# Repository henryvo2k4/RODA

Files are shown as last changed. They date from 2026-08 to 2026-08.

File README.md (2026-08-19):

# RODA

<div align="center">
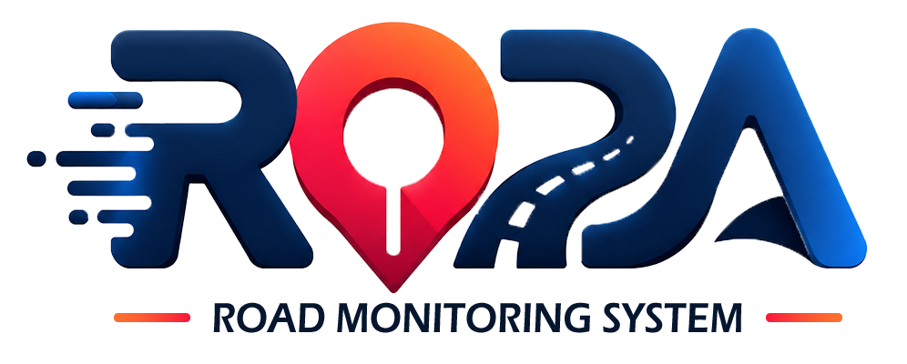
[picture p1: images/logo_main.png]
RODA Logo
  

  <h1>RODA (Road Monitoring System)</h1>
  <p><b>An End-to-End Intelligent Transportation System (ITS) for Real-time Urban Infrastructure Monitoring</b></p>
  
  
  
  
  
  
  
</div>

---

## Overview

**RODA** is an IoT-GIS road monitoring system developed as an individual
graduation project.

The system combines embedded IoT devices, cloud services, AI-based image
verification, GIS technologies, Web applications, and an Android application
to monitor and manage urban road incidents.

### Supported Incidents

| Incident | Detection Method |
|---|---|
| 🕳️ Pothole | ESP32 + MPU6050 |
| 🌊 Flooding | ESP32 + JSN-SR04T |
| 🚧 Construction | AI image verification |
| 📍 Road incidents | GPS / GIS |

---

## System Architecture

RODA consists of four major layers:

```text
┌───────────────────────┐
│    EMBEDDED LAYER     │
│                       │
│  Mobile Node          │
│  Fixed Node           │
└───────────┬───────────┘
            │
            │ HTTPS / REST / JSON
            ▼
┌───────────────────────┐
│     CLOUD LAYER       │
│                       │
│  Supabase             │
│  PostgreSQL           │
│  Storage              │
└───────────┬───────────┘
            │
      ┌─────┴─────┐
      ▼           ▼
┌───────────┐ ┌────────────────┐
│ AI / GIS  │ │ APPLICATIONS   │
│           │ │                │
│ YOLOv8    │ │ Android        │
│ Leaflet   │ │ Web Dashboard  │
└───────────┘ └────────────────┘
```

---

# Embedded System

RODA uses two ESP32-based IoT nodes designed for different monitoring
scenarios.

## Mobile Node

The Mobile Node is designed to be installed on a moving vehicle for
road-surface monitoring.

### Hardware

- ESP32
- MPU6050
- NEO-6M GPS
- MicroSD
- 18650 Li-ion Battery
- TP4056

### Functions

- Detect potholes from vehicle acceleration.
- Acquire GPS coordinates.
- Store incident data locally.
- Synchronize stored data with the cloud.
- Continue monitoring without an active Internet connection.

### Pothole Detection

The MPU6050 continuously measures acceleration.

The system processes the Z-axis acceleration and triggers a pothole event
when the configured threshold is exceeded.

```text
MPU6050
   │
   ▼
Acceleration Sampling
   │
   ▼
Z-axis Processing
   │
   ▼
Threshold Detection
   │
   ├── Normal
   │
   └── Pothole Detected
            │
            ▼
         Read GPS
            │
            ▼
      Store to MicroSD
```

---

## Store-and-Forward

A key feature of the Mobile Node is the **Store-and-Forward architecture**.

The system separates road monitoring from cloud synchronization.

### Sensing

```text
Vehicle Moving
      │
      ▼
Read MPU6050
      │
      ▼
Detect Pothole
      │
      ▼
Read GPS
      │
      ▼
Store Lat / Lng / Time
to MicroSD
```

### Synchronization

```text
Vehicle Stops
      │
      ▼
Start Synchronization
      │
      ▼
Enable Wi-Fi
      │
      ▼
Read Local Data
      │
      ▼
Create JSON Payload
      │
      ▼
HTTP POST
      │
      ▼
Supabase
```

This allows the device to continue collecting incident data during network
outages and synchronize the stored records when connectivity is restored.

---

# Fixed Node

The Fixed Node is designed for outdoor deployment at flood-prone locations.

### Hardware

- ESP32
- JSN-SR04T waterproof ultrasonic sensor
- Solar panel
- 18650 Li-ion battery
- Power management circuitry

### Functions

- Measure water level.
- Calculate flooding depth.
- Detect configurable flood thresholds.
- Send incident alerts to the cloud.
- Operate periodically using Deep Sleep.

### Flood Detection

```text
JSN-SR04T
    │
    ▼
Measure Distance
    │
    ▼
Compare with Reference Distance
    │
    ▼
Calculate Water Level
    │
    ├── Normal
    │
    └── Flood Detected
             │
             ▼
       Create JSON Payload
             │
             ▼
        HTTPS / REST API
             │
             ▼
          Supabase
```

---

# Low-Power Design

The Fixed Node uses periodic wake-up and **ESP32 Deep Sleep** to reduce
energy consumption.

```text
       ┌──────────────┐
       │  Deep Sleep  │
       └──────┬───────┘
              │
              ▼
         Wake Up Timer
              │
              ▼
         Read Sensor
              │
              ▼
       Process Water Level
              │
              ▼
        Send Data via Wi-Fi
              │
              ▼
         Return to Sleep
```

### Measured Results

| State | Current |
|---|---:|
| Active / Wi-Fi | ~120 mA |
| Deep Sleep | ~15 µA |
| Average | ~1.35 mA |

---

# Cloud & Data Pipeline

RODA uses **Supabase** as the cloud backend.

### Components

- PostgreSQL
- REST API
- Supabase Storage
- HTTPS
- JSON

### Data Flow

```text
ESP32
  │
  │ JSON
  ▼
HTTPS REST API
  │
  ▼
Supabase
  │
  ├── PostgreSQL
  ├── Storage
  └── API
       │
       ├── Android
       ├── Web
       └── AI Service
```

Each IoT node is identified using a unique `device_id`.

Example payload:

```json
{
  "device_id": "NODE_CODINH_01",
  "lat": 10.732,
  "lng": 106.721,
  "type": "Flood",
  "status": "approved",
  "description": "Flood detected",
  "created_at": "2026-05-18T14:30:00+07:00"
}
```

---

# AI & GIS

## AI Incident Verification

RODA integrates an AI pipeline for image-based incident verification.

### Stack

- Python
- YOLOv8
- Hugging Face

### Detection Classes

- Pothole
- Flood
- Construction

### Pipeline

```text
Incident Image
      │
      ▼
AI Service
      │
      ▼
YOLOv8
      │
      ▼
Object Detection
      │
      ▼
Confidence Evaluation
      │
      ▼
Incident Verification
      │
      ▼
Cloud Status Update
```

---

## GIS

The GIS layer provides geographic visualization and spatial processing of
road incidents.

### Technologies

- OpenStreetMap
- Leaflet.js
- Turf.js
- OSRM
- Overpass API
- OSMDroid

### Features

- Interactive incident map
- GPS-based incident markers
- Road visualization
- Route calculation
- Road snapping
- Spatial processing
- Incident filtering

---

# Applications

## Android Application

<p align="center">
  
</p>

The Android application provides mobile access to the RODA platform.

### Features

- Report road incidents
- Capture incident images
- Acquire location
- View incidents on GIS maps
- Access cloud data
- Submit images for AI verification
- Routing and map interaction

### Technology

**Java · Android SDK · OSMDroid · OkHttp**

---

## Web Dashboard

The Web Dashboard provides centralized monitoring and management of road
incident data.

### Features

- GIS incident visualization
- Incident management
- Device monitoring
- Data filtering
- Road-event visualization
- Administrative functions

### Technology

**HTML · CSS · JavaScript · Leaflet.js · OpenStreetMap · REST API**

---

# Communication

RODA integrates multiple communication interfaces across the embedded and
cloud layers.

| Interface | Application |
|---|---|
| **I²C** | ESP32 ↔ MPU6050 |
| **UART** | ESP32 ↔ GPS |
| **SPI** | ESP32 ↔ MicroSD |
| **Wi-Fi** | ESP32 ↔ Internet |
| **HTTPS** | IoT ↔ Cloud |
| **REST API** | Cloud ↔ Applications |
| **JSON** | Data Exchange |

---

# Results

## Mobile Node

The Store-and-Forward mechanism was tested under different operating
conditions.

| Test | Result |
|---|---:|
| 30 km/h | 10/10 synchronized |
| 50 km/h | 7/7 synchronized |
| Network unavailable | 15/15 synchronized |
| Observed data loss | **0%** |

## Fixed Node

JSN-SR04T measurements produced errors of approximately:

**0.1 – 0.3 cm**

| Scenario | Actual | Measured | Error |
|---|---:|---:|---:|
| Dry road | 100 cm | 99.8 cm | 0.2 cm |
| Water rising | 98 cm | 98.1 cm | 0.1 cm |
| Light flooding | 94 cm | 94.3 cm | 0.3 cm |
| Deep flooding | 79 cm | 79.2 cm | 0.2 cm |

---

# Technology Stack

### Embedded

`C/C++` `ESP32` `MPU6050` `JSN-SR04T` `NEO-6M` `MicroSD`
`I²C` `UART` `SPI` `Wi-Fi` `Deep Sleep`

### Cloud

`Supabase` `PostgreSQL` `REST API` `HTTPS` `JSON`
`Supabase Storage`

### AI

`Python` `YOLOv8` `Hugging Face`

### GIS

`OpenStreetMap` `Leaflet.js` `Turf.js` `OSRM`
`Overpass API` `OSMDroid`

### Applications

`Java` `Android SDK` `HTML` `CSS` `JavaScript` `Vercel`

---

# Repository Structure

```text
RODA/
│
├── hardware/
│   ├── NodeDiDong/
│   ├── NodeCoDinh/
│   └── schematics/
│
├── android/
│
├── web/
│
├── ai/
│
├── images/
│   ├── logo_main.png
│   ├── system-architecture.png
│   ├── mobile-node.jpg
│   ├── fixed-node.jpg
│   ├── web-dashboard.png
│   └── android-app.png
│
└── README.md
```

---

# Project Status

| Component | Status |
|---|---|
| Mobile IoT Node | ✅ Completed |
| Fixed IoT Node | ✅ Completed |
| Store-and-Forward | ✅ Completed |
| Cloud Backend | ✅ Completed |
| AI Verification | ✅ Completed |
| GIS Platform | ✅ Completed |
| Android Application | ✅ Completed |
| Web Dashboard | ✅ Completed |

---

# Author

<p align="center">
  <strong>Henry</strong><br>
  Embedded Systems & IoT Developer
</p>

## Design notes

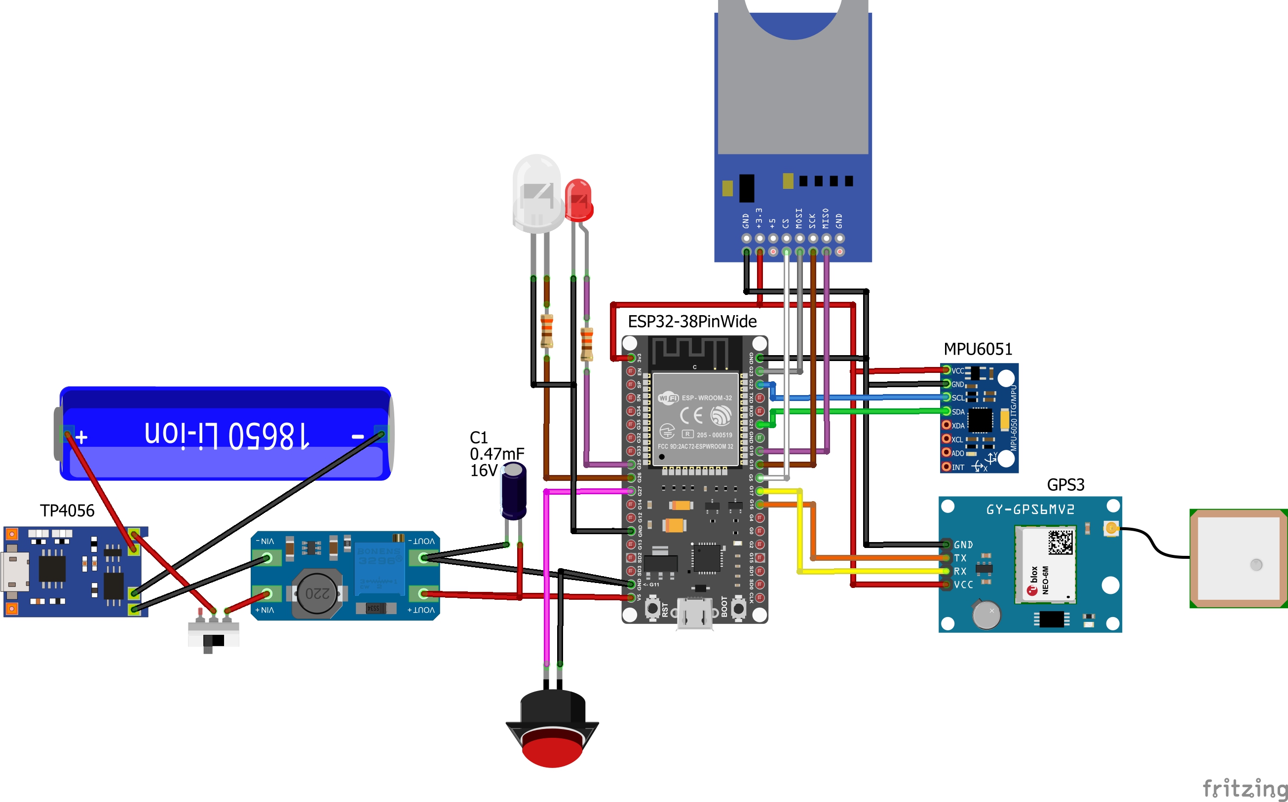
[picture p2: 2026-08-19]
hardware/schematics/Node_DiDong.jpg

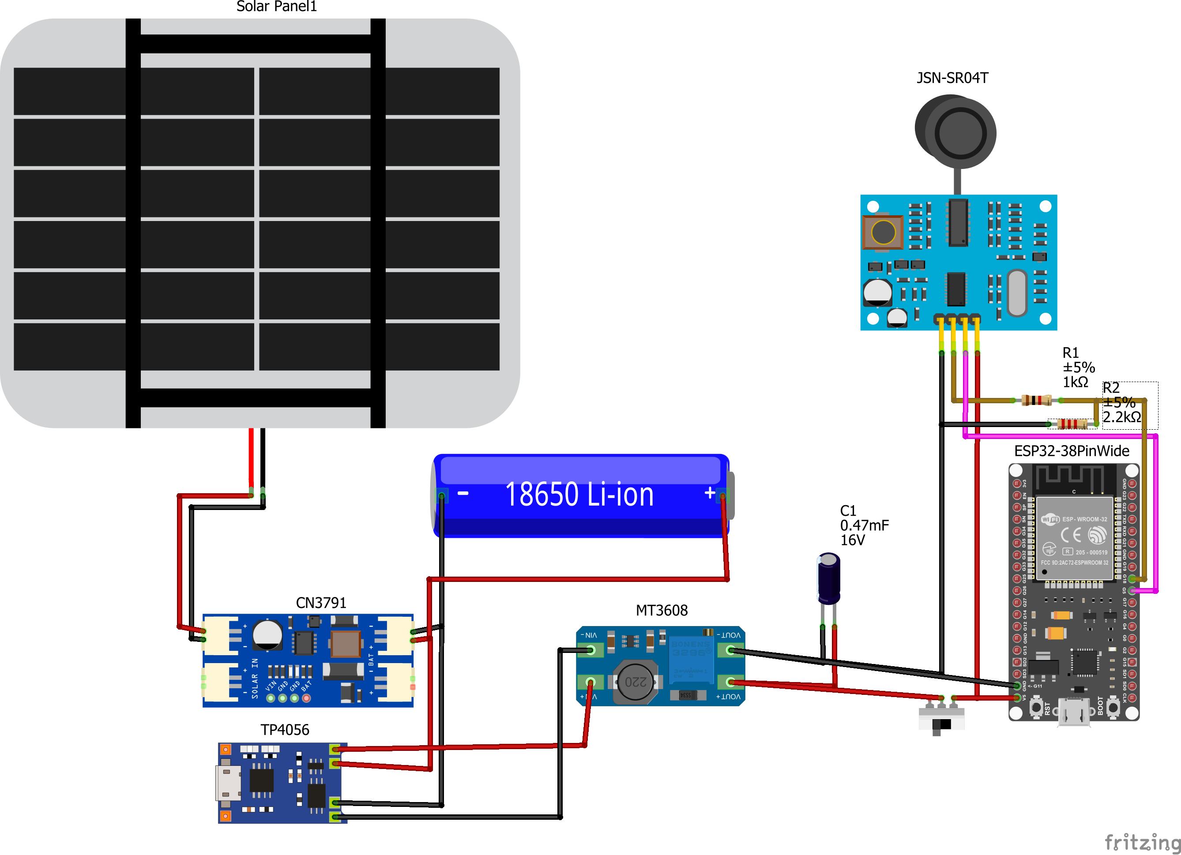
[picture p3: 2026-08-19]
hardware/schematics/Node_CoDinh.png

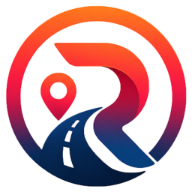
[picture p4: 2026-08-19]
images/android-chrome-192x192.png

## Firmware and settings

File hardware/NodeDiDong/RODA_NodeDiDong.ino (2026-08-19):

#include <WiFi.h>
#include <WiFiManager.h> // Thư viện cấu hình WiFi tự động
#include <HTTPClient.h>
#include <Wire.h>
#include <Adafruit_MPU6050.h>
#include <Adafruit_Sensor.h>
#include <TinyGPSPlus.h>
#include <SD.h>
#include <SPI.h>
#include <ArduinoJson.h>

// ================= CẤU HÌNH SUPABASE =================
const String SUPABASE_URL = "https://sweqvobmlntyhyeuurfr.supabase.co/rest/v1/road_events";
const String SUPABASE_KEY = "sb_publishable_xsqRVFRoQSh0c9wzwc5vxA_Hw9aj9fF";
const String DEVICE_ID = "NODE_DIDONG_01"; // Khai báo mã thiết bị di động

// ================= CẤU HÌNH CHÂN (PINS) =================
#define GPS_RX_PIN 16
#define GPS_TX_PIN 17
#define SD_CS_PIN 5 

#define LED_POWER_PIN 25 // LED 1: Báo nguồn / Trạng thái
#define LED_WIFI_PIN 26  // LED 2: Báo WiFi
#define BTN_SYNC_PIN 27  // Nút nhấn đồng bộ (Nối với GND)

// ================= CẤU HÌNH CẢM BIẾN & THẺ NHỚ =================
Adafruit_MPU6050 mpu;
TinyGPSPlus gps;
bool sdReady = false; 

// ================= THÔNG SỐ THUẬT TOÁN HỐ GÀ =================
float emaAccel = 9.81;
const float EMA_ALPHA = 0.05;
const float ACCEL_DELTA_THRESHOLD = 5.0; 
const float GYRO_MAG_THRESHOLD = 0.5;    

unsigned long lastReportTime = 0;
const unsigned long COOLDOWN_TIME = 10000; 

// ================= QUẢN LÝ GPS =================
float lastValidLat = 0.0;
float lastValidLng = 0.0;
bool hasValidGPS = false;

// ================= QUẢN LÝ TRẠNG THÁI =================
enum SystemState {
  STATE_SENSING, 
  STATE_SYNCING  
};
SystemState currentState = STATE_SENSING;

unsigned long lastDebugTime = 0;
const unsigned long DEBUG_INTERVAL = 2000;

int lastBtnState = HIGH;
unsigned long lastDebounceTime = 0;
const unsigned long DEBOUNCE_DELAY = 50;

// ================= HÀM TIỆN ÍCH =================
void updateGPS() {
  while (Serial2.available() > 0) {
    if (gps.encode(Serial2.read())) {
      if (gps.location.isValid()) {
        lastValidLat = gps.location.lat();
        lastValidLng = gps.location.lng();
        hasValidGPS = true;
      }
    }
  }
}

// ================= HÀM SETUP =================
void setup() {
  Serial.begin(115200);
  Serial2.begin(9600, SERIAL_8N1, GPS_RX_PIN, GPS_TX_PIN);

  pinMode(LED_POWER_PIN, OUTPUT);
  pinMode(LED_WIFI_PIN, OUTPUT);
  pinMode(BTN_SYNC_PIN, INPUT_PULLUP); 

  digitalWrite(LED_POWER_PIN, HIGH);
  digitalWrite(LED_WIFI_PIN, LOW);
  
  Serial.println("\n--- KHỞI ĐỘNG HỆ THỐNG NODE DI ĐỘNG ---");

  if (!mpu.begin()) {
    Serial.println("[LỖI] Không tìm thấy MPU6050!");
    while (1) { delay(10); } 
  }
  mpu.setAccelerometerRange(MPU6050_RANGE_8_G);
  mpu.setGyroRange(MPU6050_RANGE_500_DEG);
  mpu.setFilterBandwidth(MPU6050_BAND_21_HZ); 
  Serial.println("[MPU] Khởi tạo thành công!");

  if (!SD.begin(SD_CS_PIN)) {
    Serial.println("[LỖI] Không tìm thấy thẻ SD hoặc thẻ bị hỏng!");
    sdReady = false;
  } else {
    Serial.println("[SD] Khởi tạo thành công!");
    sdReady = true;
  }

  Serial.println("[WIFI] Đang kiểm tra WiFi / Mở AP cài đặt...");
  WiFiManager wm;
  wm.setConfigPortalTimeout(60); 

  if (!wm.autoConnect("RODA_NodeDiDong")) {
    Serial.println("Quá 60s không có mạng. Chuyển sang CHẾ ĐỘ OFFLINE!");
    digitalWrite(LED_WIFI_PIN, LOW); 
  } else {
    Serial.println("Đã kết nối WiFi thành công! (CHẾ ĐỘ ONLINE)");
    digitalWrite(LED_WIFI_PIN, HIGH); 
  }

  for(int i = 0; i < 3; i++){
    digitalWrite(LED_POWER_PIN, LOW); delay(200);
    digitalWrite(LED_POWER_PIN, HIGH); delay(200);
  }

  Serial.println("--- SẴN SÀNG HOẠT ĐỘNG ---\n");
}

// ================= HÀM LOOP CHÍNH =================
void loop() {
  
  updateGPS();

  // Kiểm tra trạng thái đèn WiFi
  if (WiFi.status() == WL_CONNECTED) {
    digitalWrite(LED_WIFI_PIN, HIGH);
  } else {
    digitalWrite(LED_WIFI_PIN, LOW);
  }

  // ---------------------------------------------------------
  // TRẠNG THÁI 1: CHẠY XE (ĐỌC CẢM BIẾN & XỬ LÝ SỰ CỐ)
  // ---------------------------------------------------------
  if (currentState == STATE_SENSING) {
    
    sensors_event_t a, g, temp;
    mpu.getEvent(&a, &g, &temp);

    float totalAccel = sqrt(a.acceleration.x * a.acceleration.x + 
                            a.acceleration.y * a.acceleration.y + 
                            a.acceleration.z * a.acceleration.z);

    emaAccel = EMA_ALPHA * totalAccel + (1.0 - EMA_ALPHA) * emaAccel;
    float delta = fabs(totalAccel - emaAccel);

    float gyroMagnitude = sqrt(g.gyro.x * g.gyro.x + 
                               g.gyro.y * g.gyro.y + 
                               g.gyro.z * g.gyro.z);

    if (delta > ACCEL_DELTA_THRESHOLD && gyroMagnitude > GYRO_MAG_THRESHOLD) {
      if (millis() - lastReportTime > COOLDOWN_TIME) {
        lastReportTime = millis(); 
        
        Serial.println("\n💥 PHÁT HIỆN HỐ GÀ!");
        Serial.printf("Delta Gia tốc: %.2f m/s2 | Độ chao đảo Gyro: %.2f Rad/s\n", delta, gyroMagnitude);

        if (hasValidGPS) {
          // [THAY ĐỔI]: Xử lý logic Online/Offline ngay khi phát hiện
          if (WiFi.status() == WL_CONNECTED) {
            Serial.println("🌐 Đang ở chế độ ONLINE - Gửi trực tiếp lên database...");
            bool success = sendDataAPI(lastValidLat, lastValidLng);
            if (!success) {
              Serial.println("⚠️ Gửi thất bại, lưu tạm vào thẻ nhớ để chờ đồng bộ sau!");
              savePotholeToSD(lastValidLat, lastValidLng);
            }
          } else {
            Serial.println("📴 Đang ở chế độ OFFLINE - Lưu sự cố vào thẻ nhớ...");
            savePotholeToSD(lastValidLat, lastValidLng);
          }
        } else {
          Serial.println("⚠️ Mất sóng GPS chưa có tọa độ. BỎ QUA ĐIỂM NÀY!");
        }
      }
    }

    if (millis() - lastDebugTime > DEBUG_INTERVAL) {
      Serial.println("\n=============== ĐANG CHẠY XE ===============");
      Serial.printf("Trạng thái mạng: %s\n", (WiFi.status() == WL_CONNECTED) ? "ONLINE" : "OFFLINE");
      Serial.printf("🧭 Vector Tổng: %.2f | Nền EMA: %.2f | Delta: %.2f\n", totalAccel, emaAccel, delta);
      Serial.printf("🌀 Vector Gyro: %.2f\n", gyroMagnitude);
      Serial.printf("🛰️  GPS Tọa độ chốt: %.6f, %.6f\n", lastValidLat, lastValidLng);
      Serial.println("==============================================");
      lastDebugTime = millis();
    }

    // Lắng nghe Nút Nhấn (Debounce)
    int currentBtnReading = digitalRead(BTN_SYNC_PIN);
    
    if (currentBtnReading != lastBtnState) {
      lastDebounceTime = millis();
    }

    if ((millis() - lastDebounceTime) > DEBOUNCE_DELAY) {
      if (currentBtnReading == LOW && currentState == STATE_SENSING) {
        // [THAY ĐỔI]: Nút chỉ hoạt động khi đang Offline
        if (WiFi.status() != WL_CONNECTED) {
          Serial.println("\n[NÚT NHẤN] Thiết bị đang Offline. Bắt đầu tìm WiFi và đồng bộ...");
          currentState = STATE_SYNCING;
        } else {
          Serial.println("\n[NÚT NHẤN] Thiết bị ĐÃ ONLINE sẵn. Các sự kiện đã tự động đẩy lên Database.");
        }
      }
    }
    lastBtnState = currentBtnReading;
  }

  // ---------------------------------------------------------
  // TRẠNG THÁI 2: DỪNG ĐỖ & ĐỒNG BỘ DỮ LIỆU TỪ THẺ NHỚ
  // ---------------------------------------------------------
  else if (currentState == STATE_SYNCING) {
    digitalWrite(LED_POWER_PIN, LOW); 
    
    // Gọi WiFi.begin() không tham số để tự động kết nối lại mạng đã lưu trong NVS của WiFiManager
    if (WiFi.status() != WL_CONNECTED) {
      Serial.println("Đang tìm và kết nối WiFi đã lưu để đẩy dữ liệu...");
      WiFi.begin(); 
      int attempts = 0;
      while (WiFi.status() != WL_CONNECTED && attempts < 20) { // Đợi tối đa ~10 giây
        delay(500);
        Serial.print(".");
        attempts++;
        updateGPS(); 
      }
    }

    if (WiFi.status() == WL_CONNECTED) {
      Serial.println("\nWiFi OK. Bắt đầu đẩy dữ liệu lưu trữ từ thẻ nhớ...");
      digitalWrite(LED_WIFI_PIN, HIGH);
      
      syncDataWithSupabase();
      
    } else {
      Serial.println("\nLỗi: Không tìm thấy WiFi đã lưu hoặc kết nối thất bại!");
      digitalWrite(LED_WIFI_PIN, LOW);
    }

    lastBtnState = digitalRead(BTN_SYNC_PIN); 
    digitalWrite(LED_POWER_PIN, HIGH); 
    currentState = STATE_SENSING;
    Serial.println("\n--- TIẾP TỤC ĐO ĐẠC HỐ GÀ ---");
  }
}

// ================= CÁC HÀM XỬ LÝ DỮ LIỆU =================

void savePotholeToSD(float lat, float lng) {
  if (!sdReady) {
    Serial.println("❌ Lỗi: Thẻ SD không sẵn sàng. Hủy thao tác ghi để chống crash.");
    return;
  }

  File file = SD.open("/unsent.txt", FILE_APPEND);
  if (file) {
    file.print(lat, 6);
    file.print(",");
    file.println(lng, 6);
    file.close();
    Serial.println("📁 Đã lưu vào thẻ nhớ thành công!");
  } else {
    Serial.println("❌ Lỗi: Có thẻ SD nhưng không thể mở file để ghi!");
  }
}

bool sendDataAPI(float lat, float lng) {
  StaticJsonDocument<200> doc;
  doc["lat"] = lat;
  doc["lng"] = lng;
  doc["type"] = "Hố gà";
  doc["device_id"] = DEVICE_ID; 
  doc["description"] = "Cảnh báo tự động từ phương tiện (Đã đồng bộ).";
  doc["status"] = "approved";
  doc["image_url"] = "[]";

  String requestBody;
  serializeJson(doc, requestBody);

  bool success = false;

  for (int retry = 1; retry <= 3; retry++) {
    HTTPClient http;
    http.setTimeout(10000); 
    http.begin(SUPABASE_URL);

    http.addHeader("apikey", SUPABASE_KEY);
    http.addHeader("Authorization", "Bearer " + SUPABASE_KEY);
    http.addHeader("Content-Type", "application/json");
    http.addHeader("Prefer", "return=minimal");

    Serial.printf("  -> Lần thử API %d/3... ", retry);
    int httpResponseCode = http.POST(requestBody);
    
    Serial.printf("Mã HTTP: %d\n", httpResponseCode);

    if (httpResponseCode >= 200 && httpResponseCode < 300) {
      success = true;
      http.end();
      break; 
    } 

    http.end();
    
    unsigned long waitStart = millis();
    while (millis() - waitStart < 1000) {
      updateGPS();
      delay(10);
    }
  }

  return success;
}

void syncDataWithSupabase() {
  if (!sdReady) {
    Serial.println("❌ Lỗi: Thẻ SD không sẵn sàng. Không thể đồng bộ.");
    return;
  }

  if (!SD.exists("/unsent.txt")) {
    Serial.println("✅ Thẻ nhớ sạch: Không có dữ liệu hố gà nào cần đồng bộ.");
    return;
  }
  
  Serial.println("\n🔄 Đang xử lý file unsent.txt...");
  SD.rename("/unsent.txt", "/sync.txt");

  File syncFile = SD.open("/sync.txt", FILE_READ);
  File failFile = SD.open("/unsent.txt", FILE_APPEND); 

  if (!syncFile) {
    Serial.println("❌ Lỗi: Không mở được file sync.txt");
    return;
  }

  int count = 0;
  while (syncFile.available()) {
    updateGPS();

    String line = syncFile.readStringUntil('\n');
    line.trim();
    if (line.length() == 0) continue;

    int commaIndex = line.indexOf(',');
    if (commaIndex > 0) {
      String latStr = line.substring(0, commaIndex);
      String lngStr = line.substring(commaIndex + 1);
                 
      float lat = latStr.toFloat();
      float lng = lngStr.toFloat();

      bool success = sendDataAPI(lat, lng);
      
      if (success) {
        Serial.printf("✅ Gửi OK: %s, %s\n", latStr.c_str(), lngStr.c_str());
        count++;
      } else {
        Serial.printf("❌ Gửi LỖI 3 LẦN: %s, %s -> Trả lại vào thẻ nhớ.\n", latStr.c_str(), lngStr.c_str());
        if (failFile) failFile.println(line); 
      }
    }
  }

  syncFile.close();
  if (failFile) failFile.close();

  SD.remove("/sync.txt"); // Dữ liệu đồng bộ xong sẽ bị làm sạch an toàn
  if (count > 0) {
    Serial.printf("🎉 Đồng bộ hoàn tất! Tải lên %d sự kiện thành công.\n\n", count);
  } else {
    Serial.println("⚠️ Không có sự kiện nào được tải lên hoặc toàn bộ đều lỗi mạng.");
  }
}

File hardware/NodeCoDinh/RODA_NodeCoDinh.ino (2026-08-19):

#include <WiFi.h>
#include <WiFiManager.h>
#include <HTTPClient.h>
#include <WiFiClientSecure.h>
#include <ArduinoJson.h>

// ================= CẤU HÌNH PHẦN CỨNG =================
#define TRIG_PIN 5
#define ECHO_PIN 18
#define POWER_LED_PIN 4 

// ================= THÔNG TIN WIFI CỐ ĐỊNH =================
const char* default_ssid = "Henry";
const char* default_password = "88888888";

// ================= CẤU HÌNH SUPABASE =================
const String SUPABASE_URL = "https://sweqvobmlntyhyeuurfr.supabase.co";
const String SUPABASE_KEY = "sb_publishable_xsqRVFRoQSh0c9wzwc5vxA_Hw9aj9fF";
const String DEVICE_ID = "NODE_CODINH_01"; 

// ================= THÔNG SỐ VẬN HÀNH & CHỐNG NHIỄU =================
const int SLEEP_MINUTES = 15;
const float FLOOD_THRESHOLD = 1.0;         // Ngưỡng bắt đầu tính là ngập (cm)
#define WATER_CHANGE_THRESHOLD 1.0         // Ngưỡng thay đổi mực nước tối thiểu để UPDATE (tránh spam DB do nhiễu cảm biến)

float base_distance = 0;
float node_lat = 0;
float node_lng = 0;

void setup() {
  Serial.begin(115200);
  
  // Khởi tạo và bật LED báo nguồn ngay khi vừa thức dậy
  pinMode(POWER_LED_PIN, OUTPUT);
  digitalWrite(POWER_LED_PIN, HIGH);

  pinMode(TRIG_PIN, OUTPUT);
  pinMode(ECHO_PIN, INPUT);

  Serial.println("\n--- KHỞI ĐỘNG TRẠM QUAN TRẮC NGẬP LỤT (WIFI & SUPABASE EVENT MANAGEMENT) ---");

  // 1. ĐO SÓNG SIÊU ÂM
  float current_distance = getAverageDistance();
  if (current_distance < 0) {
    Serial.println("❌ Lỗi: Cảm biến siêu âm bị nhiễu hoặc không phản hồi.");
    goToSleep();
  }
  Serial.printf("📏 Khoảng cách cảm biến đo được: %.2f cm\n", current_distance);

  // 2. KẾT NỐI WIFI
  Serial.println("\nĐang thử kết nối WiFi mặc định trong code...");
  WiFi.begin(default_ssid, default_password);
  
  int attempts = 0;
  while (WiFi.status() != WL_CONNECTED && attempts < 20) { 
    delay(500);
    Serial.print(".");
    attempts++;
  }

  if (WiFi.status() != WL_CONNECTED) {
    Serial.println("\n⚠️ Không thấy WiFi mặc định. Chuyển sang quét mạng đã lưu hoặc mở AP...");
    WiFiManager wm;
    wm.setConfigPortalTimeout(180); 
    
    if (!wm.autoConnect("RODA_NodeCoDinh")) {
      Serial.println("❌ Không ai cấu hình mạng hoặc rớt mạng. Đi ngủ chờ lần sau...");
      goToSleep();
    }
  }
  
  Serial.print("\n✅ Đã kết nối WiFi thành công! IP: ");
  Serial.println(WiFi.localIP());

  // 3. ĐỒNG BỘ THỜI GIAN (NTP) TRƯỚC KHI XỬ LÝ
  Serial.print("⏳ Đang đồng bộ thời gian (NTP)...");
  // Dùng UTC 0 để format ra chuỗi chuẩn Z (Zulu Time) gửi lên Supabase
  configTime(0, 0, "pool.ntp.org", "time.nist.gov"); 
  int ntpRetry = 0;
  while (time(nullptr) < 100000 && ntpRetry < 10) {
    delay(500);
    Serial.print(".");
    ntpRetry++;
  }
  Serial.println(" Hoàn tất!");

  // 4. TẢI CẤU HÌNH TỪ SUPABASE (Bảng devices)
  if (fetchDeviceConfig()) {
    
    // Tính mức ngập thực tế
    float water_level = base_distance - current_distance;
    if (water_level < 0) {
      water_level = 0.0; // Không để mức nước âm do sai số vật lý
    }
    Serial.printf("🌊 Mức ngập thực tế tính toán: %.2f cm\n", water_level);

    // 5. XỬ LÝ LOGIC TRẠNG THÁI SỰ KIỆN (STATE MACHINE CHO NGẬP LỤT)
    processFloodEvent(water_level);
  }

  // 6. NGẮT KẾT NỐI & ĐI NGỦ
  WiFi.disconnect(true);
  WiFi.mode(WIFI_OFF);
  Serial.println("\nĐã tắt WiFi an toàn.");
  
  goToSleep();
}

void loop() {
}

// ================= CÁC HÀM XỬ LÝ LÕI =================

void goToSleep() {
  Serial.printf("💤 Hệ thống đi ngủ sâu %d phút...\n", SLEEP_MINUTES);
  Serial.flush(); 
  
  digitalWrite(POWER_LED_PIN, LOW); // Tắt LED trước khi đi ngủ để tiết kiệm năng lượng
  
  esp_sleep_enable_timer_wakeup(SLEEP_MINUTES * 60 * 1000000ULL);
  esp_deep_sleep_start();
}

float getAverageDistance() {
  float sum = 0;
  int validReadings = 0;
  for (int i = 0; i < 5; i++) { 
    digitalWrite(TRIG_PIN, LOW); delayMicroseconds(2);
    digitalWrite(TRIG_PIN, HIGH); delayMicroseconds(10);
    digitalWrite(TRIG_PIN, LOW);
    
    long duration = pulseIn(ECHO_PIN, HIGH, 30000); 
    
    if (duration == 0) { delay(50); continue; }

    float distance = (duration * 0.0343) / 2;
    if (distance > 2.0 && distance < 450.0) {
      sum += distance;
      validReadings++;
    }
    
    if (validReadings >= 3) break; 
    delay(50);
  }

  if (validReadings == 0) return -1.0; 
  return sum / validReadings;
}


String getCurrentTimestamp() {
  time_t now = time(nullptr);
  if (now < 100000) {
    return "now"; 
  }
  
  struct tm timeinfo;
  gmtime_r(&now, &timeinfo);
  
  char buffer[30];
  // Định dạng ISO 8601 (VD: 2026-07-28T09:30:00Z)
  strftime(buffer, sizeof(buffer), "%Y-%m-%dT%H:%M:%SZ", &timeinfo);
  return String(buffer);
}

bool fetchDeviceConfig() {
  WiFiClientSecure secureClient;
  secureClient.setInsecure();
  
  HTTPClient http;
  String url = SUPABASE_URL + "/rest/v1/devices?id=eq." + DEVICE_ID + "&select=base_distance,lat,lng";
  
  Serial.println("Đang tải dữ liệu cấu hình từ Supabase...");
  http.begin(secureClient, url);
  http.addHeader("apikey", SUPABASE_KEY);
  http.addHeader("Authorization", "Bearer " + SUPABASE_KEY);

  int statusCode = http.GET();
  String response = http.getString();
  http.end();
  
  if (statusCode == 200) {
    StaticJsonDocument<256> doc;
    DeserializationError error = deserializeJson(doc, response);
    if (!error && doc.size() > 0) {
      base_distance = doc[0]["base_distance"];
      node_lat = doc[0]["lat"];
      node_lng = doc[0]["lng"];
      Serial.printf("📥 Tải thành công: Khoảng cách gốc = %.2f cm | Lat = %.6f\n", base_distance, node_lat);
      return true;
    }
  }
  
  Serial.printf("❌ Lỗi tải cấu hình! Mã lỗi: %d\n", statusCode);
  return false;
}
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

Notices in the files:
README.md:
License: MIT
